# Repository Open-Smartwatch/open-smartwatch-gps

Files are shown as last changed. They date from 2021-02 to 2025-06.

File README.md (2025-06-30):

# Open-Smartwatch KiCAD files

Repo for kicad schematic, board and gerber files. This project is in development and is not ready for release.

Update 2025-06: There never was a release since the selected GPS module does not work on a wearable-sized PCB, and while worn at the same time.

## Tools

To view/modify the files from this repository, install KiCAD from: [https://kicad.org](https://kicad.org)

Also, add the following Symbol/Footprint library to KiCAD: [https://github.com/Open-Smartwatch/Kicad-Libraries](https://github.com/Open-Smartwatch/Kicad-Libraries)

## Schematic
Schematic

## Plots
front
bottom

## BOM

See: [https://htmlpreview.github.io/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](https://htmlpreview.github.io/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)

## Instagram 
https://www.instagram.com/pauls_3d_things/

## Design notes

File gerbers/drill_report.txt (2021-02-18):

Drill report for /github/workspace/osw.kicad_pcb
Created on Thu Feb 18 17:03:41 2021

Copper Layer Stackup:
    =============================================================
    L1 :  F.Cu                      front
    L2 :  In1.Cu                    in1
    L3 :  In2.Cu                    in2
    L4 :  B.Cu                      back

Drill file 'osw-PTH.drl' contains
    plated through holes:
    =============================================================
    T1  0.33mm  0.013"  (193 holes)
    T2  0.75mm  0.030"  (2 holes)  (with 2 slots)

    Total plated holes count 195

Drill file 'osw-NPTH.drl' contains
    unplated through holes:
    =============================================================
    T1  0.55mm  0.022"  (8 holes)
    T2  1.00mm  0.039"  (4 holes)  (with 2 slots)

    Total unplated holes count 12

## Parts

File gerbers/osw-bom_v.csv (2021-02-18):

Reference | Value | Package | Quantity | digikey_pn | mpn | manufacturer | digi-key_pn | manf | manf#
Unpolarized capacitor, small symbol | 10p | C_0603_1608Metric | 1
Unpolarized capacitor, small symbol | 100p | C_0603_1608Metric | 1
Unpolarized capacitor, small symbol | 0.1u | C_0603_1608Metric | 1
Unpolarized capacitor, small symbol | 0.1u | C_0603_1608Metric | 1
Unpolarized capacitor, small symbol | 0.1u | C_0603_1608Metric | 1
Unpolarized capacitor, small symbol | 0.1u | C_0603_1608Metric | 1
Unpolarized capacitor, small symbol | 0.1u | C_0603_1608Metric | 1
Unpolarized capacitor, small symbol | 0.1u | C_0603_1608Metric | 1
Unpolarized capacitor, small symbol | 0.1u | C_0603_1608Metric | 1
Unpolarized capacitor, small symbol | 0.1u | C_0603_1608Metric | 1
Unpolarized capacitor, small symbol | 0.1u | C_0603_1608Metric | 1
Unpolarized capacitor, small symbol | 0.1u | C_0603_1608Metric | 1
Unpolarized capacitor, small symbol | 0.1u | C_0603_1608Metric | 1
Unpolarized capacitor, small symbol | 0.1u | C_0603_1608Metric | 1
Unpolarized capacitor, small symbol | 0.1u | C_0603_1608Metric | 1
Unpolarized capacitor, small symbol | 0.1u | C_0603_1608Metric | 1
Unpolarized capacitor, small symbol | 4.7uF | C_0603_1608Metric | 1
Unpolarized capacitor, small symbol | 4.7u | C_0603_1608Metric | 1
Unpolarized capacitor, small symbol | 4.7u | C_0603_1608Metric | 1
Unpolarized capacitor, small symbol | 4.7uF | C_0603_1608Metric | 1
Unpolarized capacitor, small symbol | 100u | C_1206_3216Metric | 1
Unpolarized capacitor, small symbol | 100u | C_1206_3216Metric | 1
Light emitting diode, small symbol | LED_Green | LED_0805_2012Metric | 1
Generic connector, single row, 01x02, script generated (kicad-library-utils/schlib/autogen/connector/) | Conn_01x02 | PinHeader_1x02_P2.54mm_Vertical | 1
0.115A Id, 60V Vds, N-Channel MOSFET, SOT-23 | 2N7002 | SOT-23 | 1
Resistor, small symbol | 0R | R_0402_1005Metric | 1
Resistor, small symbol | 22 | R_0603_1608Metric | 1
Resistor, small symbol | 470R | R_0603_1608Metric | 1
Resistor, small symbol | 470R | R_0603_1608Metric | 1
Resistor, small symbol | 510R | R_0603_1608Metric | 1
Resistor, small symbol | 1k | R_0603_1608Metric | 1
Resistor, small symbol | 1k | R_0603_1608Metric | 1
Resistor, small symbol | 1k | R_0603_1608Metric | 1
Resistor, small symbol | 1k | R_0603_1608Metric | 1
Resistor, small symbol | 1k | R_0603_1608Metric | 1
Resistor, small symbol | 1k | R_0603_1608Metric | 1
Resistor, small symbol | 2.2K | R_0603_1608Metric | 1
Resistor, small symbol | 5k | R_0603_1608Metric | 1
Resistor, small symbol | 5.6k | R_0603_1608Metric | 1
Resistor, small symbol | 10k | R_0603_1608Metric | 1
Resistor, small symbol | 10k | R_0603_1608Metric | 1
Resistor, small symbol | 10k | R_0603_1608Metric | 1
Resistor, small symbol | 10k | R_0603_1608Metric | 1
Resistor, small symbol | 10k | R_0603_1608Metric | 1
Resistor, small symbol | 10k | R_0603_1608Metric | 1
Resistor, small symbol | 10k | R_0603_1608Metric | 1
Resistor, small symbol | 56k | R_0603_1608Metric | 1
Resistor, small symbol | 200k | R_0603_1608Metric | 1
Resistor, small symbol | 200k | R_0603_1608Metric | 1
Resistor, small symbol | 1M | R_0603_1608Metric | 1
Push button switch, generic, two pins | SW_Push | button_side_smd | 1
Push button switch, generic, two pins | SW_Push | button_side_smd | 1
Push button switch, generic, two pins | SW_Push | button_side_smd | 1
Push button switch, generic, two pins | SW_Push | button_side_smd | 1
 | BMA400 | LGA-12_2x2mm_P0.5mm | 1 | 828-1081-1-ND | BMA400 | Bosch Sensortec
 | CH340E | MSOP-10_3x3mm_P0.5mm | 1
±5ppm, I2C Real-Time Clock SOIC-8 | DS3231MZ | SOIC-8_3.9x4.9mm_P1.27mm | 1
 | GC9A01_IPS_display | GC9A01_IPS_display | 1
 | MCP73831T-2ACI_OT | SOT-23-5 | 1 |  | MCP73831T-2ACI/OT | Microchip Technology | MCP73831T-2ACI/OTCT-ND
 | PSRAM64H | SOP-8_3.9x4.9mm_P1.27mm | 1
 | Quectel_L96 | Quectel_L96 | 1
 | TPS2115A | TSSOP-8_4.4x3mm_P0.65mm | 1 | 296-16940-1-ND | TPS2115APWR | Texas Instruments
 | USB-OTG | USBmicro-B | 1
 | XC6209 | SOT-23-5 | 1
 | XC6209 | SOT-23-5 | 1
 | ttgo-32-micro | ttgo-32-micro | 1
 | SD_ebay-uSD-push_push_SMD | Conn_uSDcard | 1 |  |  |  |  | ebay | _

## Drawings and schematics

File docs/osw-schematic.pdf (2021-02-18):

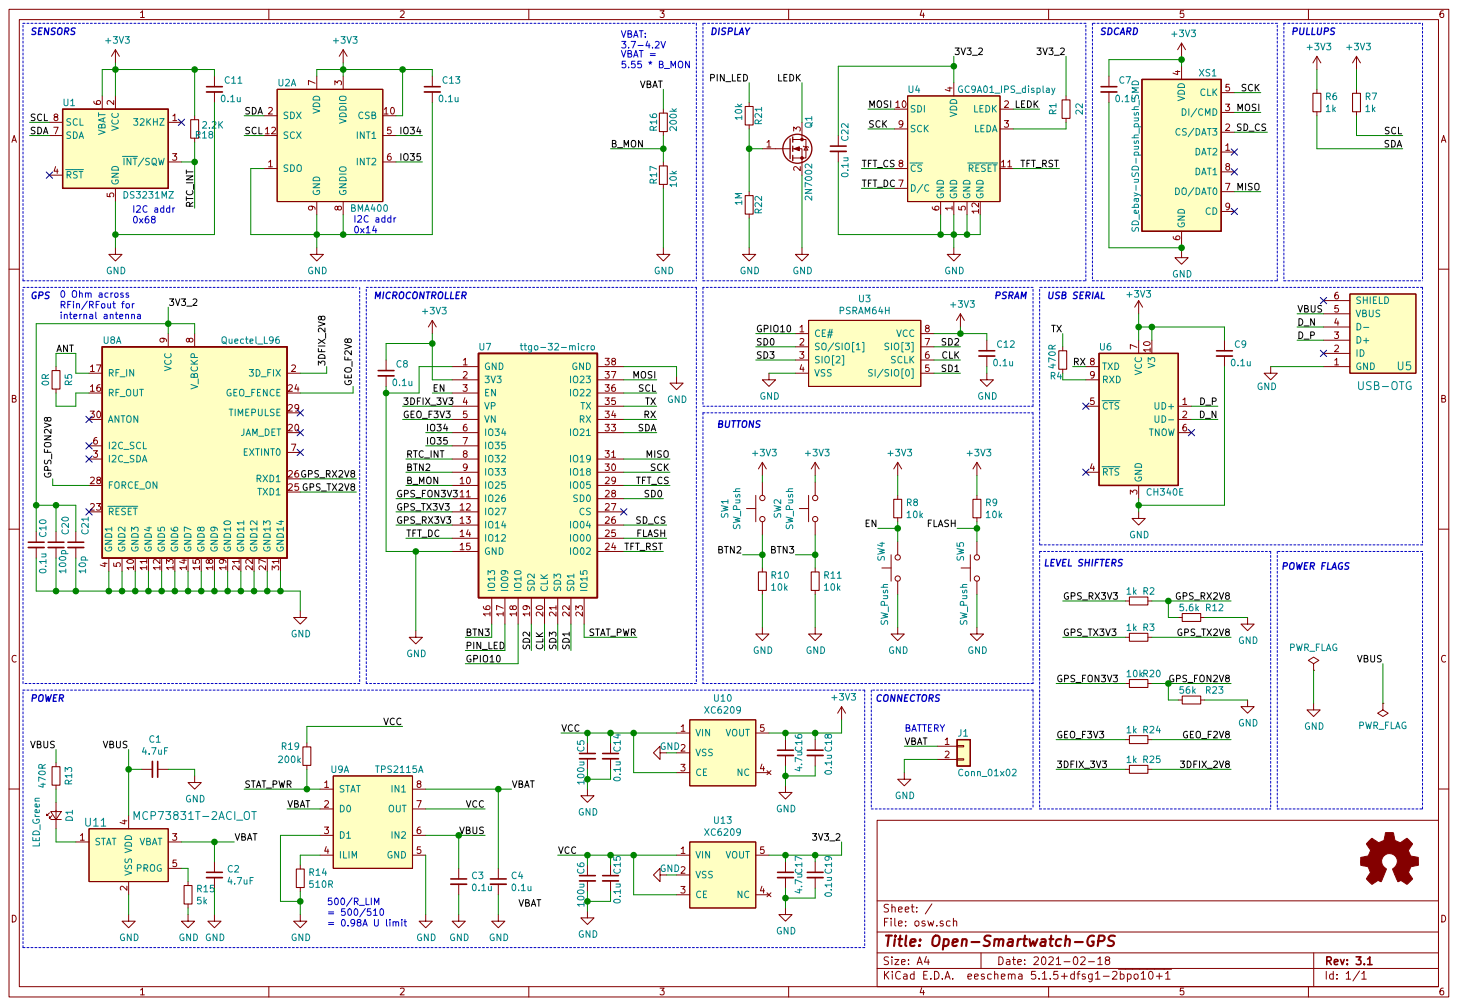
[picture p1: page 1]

6 DO/DAT0 7 DAT1 8 CD 9 XS1 SD_ebay-uSD-push_push_SMD R16 200k R17 10k GND
SCK RX MISO

6 SDA 7 SCL 8 U1 DS3231MZ GND 470R R13 EN GND

0 Ohm across RFin/RFout for

3 RTS 4 CTS 5 TNOW 6 VCC

Id: 1/1 Title: Open-Smartwatch-GPS

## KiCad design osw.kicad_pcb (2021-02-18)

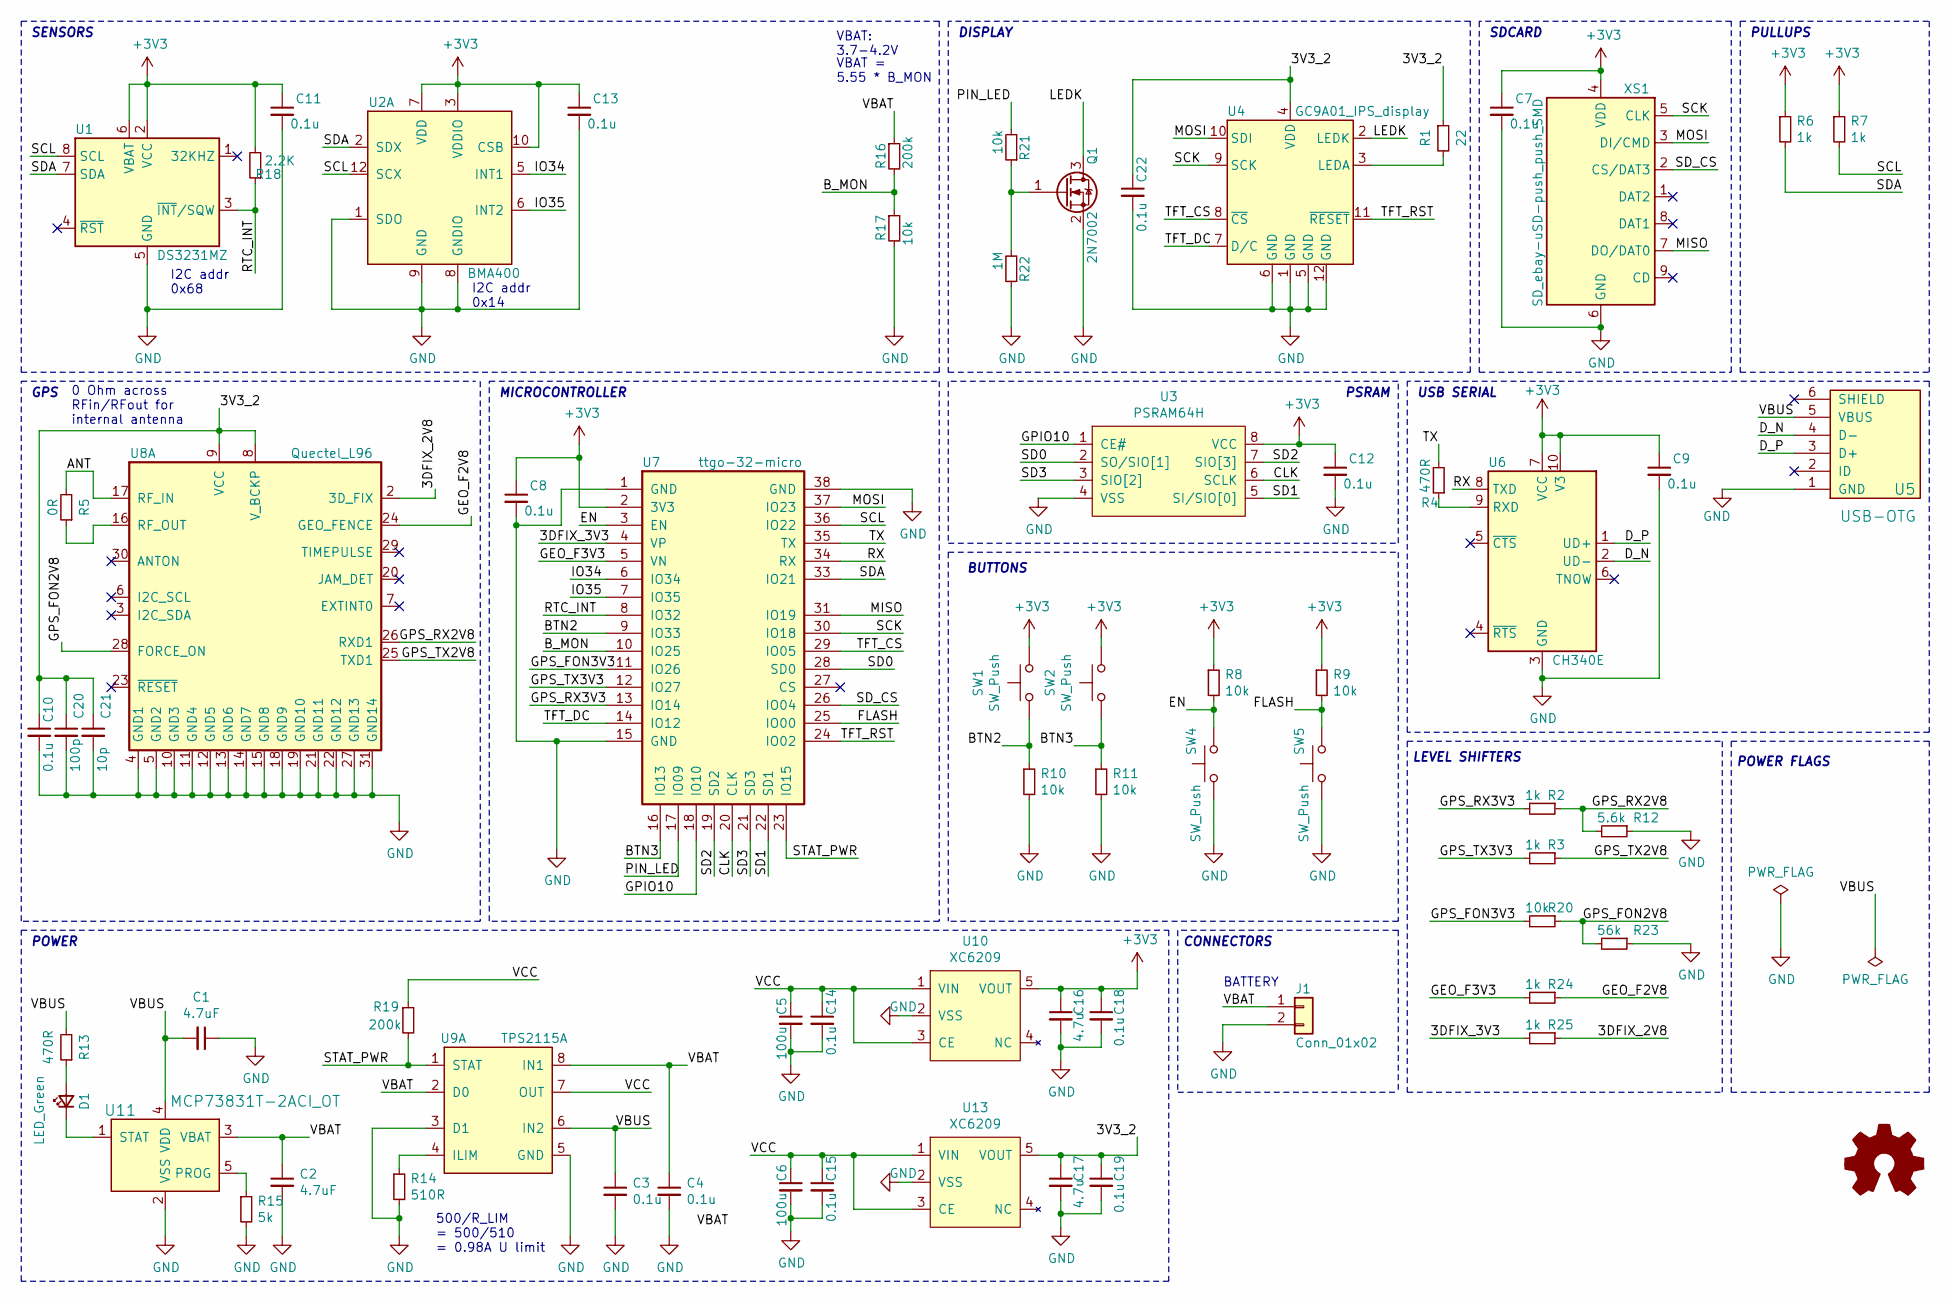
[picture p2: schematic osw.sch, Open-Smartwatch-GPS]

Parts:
C1, C2: 4.7uF; C_0603_1608Metric
C3, C4, C7, C8, C9, C10, C11, C12, C13, C14, C15, C18, C19, C22: 0.1u; C_0603_1608Metric
C5, C6: 100u; C_1206_3216Metric
C16, C17: 4.7u; C_0603_1608Metric
C20: 100p; C_0603_1608Metric
C21: 10p; C_0603_1608Metric
D1: LED_Green; LED_0805_2012Metric
J1: Conn_01x02; PinHeader_1x02_P2.54mm_Vertical
Q1: 2N7002; SOT-23
R1: 22; R_0603_1608Metric
R2, R3, R6, R7, R24, R25: 1k; R_0603_1608Metric
R4, R13: 470R; R_0603_1608Metric
R5: 0R; R_0402_1005Metric
R8, R9, R10, R11, R17, R20, R21: 10k; R_0603_1608Metric
R12: 5.6k; R_0603_1608Metric
R14: 510R; R_0603_1608Metric
R15: 5k; R_0603_1608Metric
R16, R19: 200k; R_0603_1608Metric
R18: 2.2K; R_0603_1608Metric
R22: 1M; R_0603_1608Metric
R23: 56k; R_0603_1608Metric
SW1, SW2, SW4, SW5: SW_Push; button_side_smd
U1: DS3231MZ; SOIC-8_3.9x4.9mm_P1.27mm
U2: BMA400; LGA-12_2x2mm_P0.5mm; MPN BMA400; DigiKey_PN 828-1081-1-ND
U3: PSRAM64H; SOP-8_3.9x4.9mm_P1.27mm
U4: GC9A01_IPS_display
U5: USB-OTG; USBmicro-B
U6: CH340E; MSOP-10_3x3mm_P0.5mm
U7: ttgo-32-micro
U8: Quectel_L96
U9: TPS2115A; TSSOP-8_4.4x3mm_P0.65mm; MPN TPS2115APWR; DigiKey_PN 296-16940-1-ND
U10, U13: XC6209; SOT-23-5
U11: MCP73831T-2ACI_OT; SOT-23-5; MPN MCP73831T-2ACI/OT; Digi-Key_PN MCP73831T-2ACI/OTCT-ND
XS1: SD_ebay-uSD-push_push_SMD; Conn_uSDcard

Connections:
+3V3: C7.1, C8.1, C9.1, C11.1, C12.1, C13.1, C16.1, C18.1, R6.1, R7.1, R8.1, R9.1, R18.2, SW1.2, SW2.2, U1.2 (VCC), U1.6 (VBAT), U2.3 (VDDIO), U2.7 (VDD), U2.10 (CSB), U3.8 (VCC), U6.7 (VCC), U6.10 (V3), U7.2 (3V3), U10.5 (VOUT), XS1.4 (VDD)
/3DFIX_2V8: R25.1, U8.2 (3D_FIX)
/3DFIX_3V3: R25.2, U7.4 (VP)
/3V3_2: C10.1, C17.1, C19.1, C20.1, C21.1, C22.1, R1.1, U4.4 (VDD), U8.8 (V_BCKP), U8.9 (VCC), U13.5 (VOUT)
/ANT: R5.2, U8.17 (RF_IN)
/BTN2: R10.1, SW1.1, U7.9 (IO33)
/BTN3: R11.1, SW2.1, U7.16 (IO13)
/B_MON: R16.2, R17.1, U7.10 (IO25)
/CLK: U3.6 (SCLK), U7.20 (CLK)
/D_N: U5.4 (D-), U6.2 (UD-)
/D_P: U5.3 (D+), U6.1 (UD+)
/EN: R8.2, SW4.2, U7.3 (EN)
/FLASH: R9.2, SW5.2, U7.25 (IO00)
/GEO_F2V8: R24.1, U8.24 (GEO_FENCE)
/GEO_F3V3: R24.2, U7.5 (VN)
/GPIO10: U3.1 (CE#), U7.18 (IO10)
/GPS_FON2V8: R20.1, R23.2, U8.28 (FORCE_ON)
/GPS_FON3V3: R20.2, U7.11 (IO26)
/GPS_RX2V8: R2.1, R12.2, U8.26 (RXD1)
/GPS_RX3V3: R2.2, U7.13 (IO14)
/GPS_TX2V8: R3.1, U8.25 (TXD1)
/GPS_TX3V3: R3.2, U7.12 (IO27)
/IO34: U2.5 (INT1), U7.6 (IO34)
/IO35: U2.6 (INT2), U7.7 (IO35)
/LEDK: Q1.3 (D), U4.2 (LEDK)
/MISO: U7.31 (IO19), XS1.7 (DO/DAT0)
/MOSI: U4.10 (SDI), U7.37 (IO23), XS1.3 (DI/CMD)
/PIN_LED: R21.2, U7.17 (IO09)
/RTC_INT: R18.1, U1.3 (~INT~/SQW), U7.8 (IO32)
/RX: U6.8 (TXD), U7.34 (RX)
/SCK: U4.9 (SCK), U7.30 (IO18), XS1.5 (CLK)
/SCL: R7.2, U1.8 (SCL), U2.12 (SCX), U7.36 (IO22)
/SD0: U3.2 (SO/SIO[1]), U7.28 (SD0)
/SD1: U3.5 (SI/SIO[0]), U7.22 (SD1)
/SD2: U3.7 (SIO[3]), U7.19 (SD2)
/SD3: U3.3 (SIO[2]), U7.21 (SD3)
/SDA: R6.2, U1.7 (SDA), U2.2 (SDX), U7.33 (IO21)
/SD_CS: U7.26 (IO04), XS1.2 (CS/DAT3)
/STAT_PWR: R19.2, U7.23 (IO15), U9.1 (STAT)
/TFT_CS: U4.8 (~CS), U7.29 (IO05)
/TFT_DC: U4.7 (D/C), U7.14 (IO12)
/TFT_RST: U4.11 (~RESET), U7.24 (IO02)
/TX: R4.2, U7.35 (TX)
/VBAT: C2.1, C4.1, J1.1, R16.1, U9.2 (D0), U9.8 (IN1), U11.3 (VBAT)
/VBUS: C1.2, C3.1, R13.2, U5.5 (VBUS), U9.6 (IN2), U11.4 (VDD)
/VCC: C5.1, C6.1, C14.1, C15.1, R19.1, U9.7 (OUT), U10.1 (VIN), U10.3 (CE), U13.1 (VIN), U13.3 (CE)
GND: C1.1, C2.2, C3.2, C4.2, C5.2, C6.2, C7.2, C8.2, C9.2, C10.2, C11.2, C12.2, C13.2, C14.2, C15.2, C16.2, C17.2, C18.2, C19.2, C20.2, C21.2, C22.2, J1.2, Q1.2 (S), R10.2, R11.2, R12.1, R14.2, R15.2, R17.2, R22.1, R23.1, SW4.1, SW5.1, U1.5 (GND), U2.1 (SDO), U2.8 (GNDIO), U2.9 (GND), U3.4 (VSS), U4.1 (GND), U4.5 (GND), U4.6 (GND), U4.12 (GND), U5.1 (GND), U6.3 (GND), U7.1 (GND), U7.15 (GND), U7.38 (GND), U8.4 (GND1), U8.5 (GND2), U8.10 (GND3), U8.11 (GND4), U8.12 (GND5), U8.13 (GND6), U8.14 (GND7), U8.15 (GND8), U8.18 (GND9), U8.19 (GND10), U8.21 (GND11), U8.22 (GND12), U8.27 (GND13), U8.31 (GND14), U9.3 (D1), U9.5 (GND), U10.2 (VSS), U11.2 (VSS), U13.2 (VSS), XS1.6 (GND)
unnamed: D1.1 (K), U11.1 (STAT)
unnamed: D1.2 (A), R13.1
unnamed: Q1.1 (G), R21.1, R22.2
unnamed: R1.2, U4.3 (LEDA)
unnamed: R4.1, U6.9 (RXD)
unnamed: R5.1, U8.16 (RF_OUT)
unnamed: R14.1, U9.4 (ILIM)
unnamed: R15.1, U11.5 (PROG)

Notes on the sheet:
500/R_LIM = 500/510 = 0.98A U limit
GPS
SENSORS
POWER
SDCARD
DISPLAY
USB SERIAL
BUTTONS
PULLUPS
0 Ohm across RFin/RFout for internal antenna
VBAT: 3.7-4.2V
VBAT = 5.55 * B_MON
MICROCONTROLLER
POWER FLAGS
I2C addr 0x68
I2C addr 0x14
CONNECTORS
BATTERY
LEVEL SHIFTERS
PSRAM

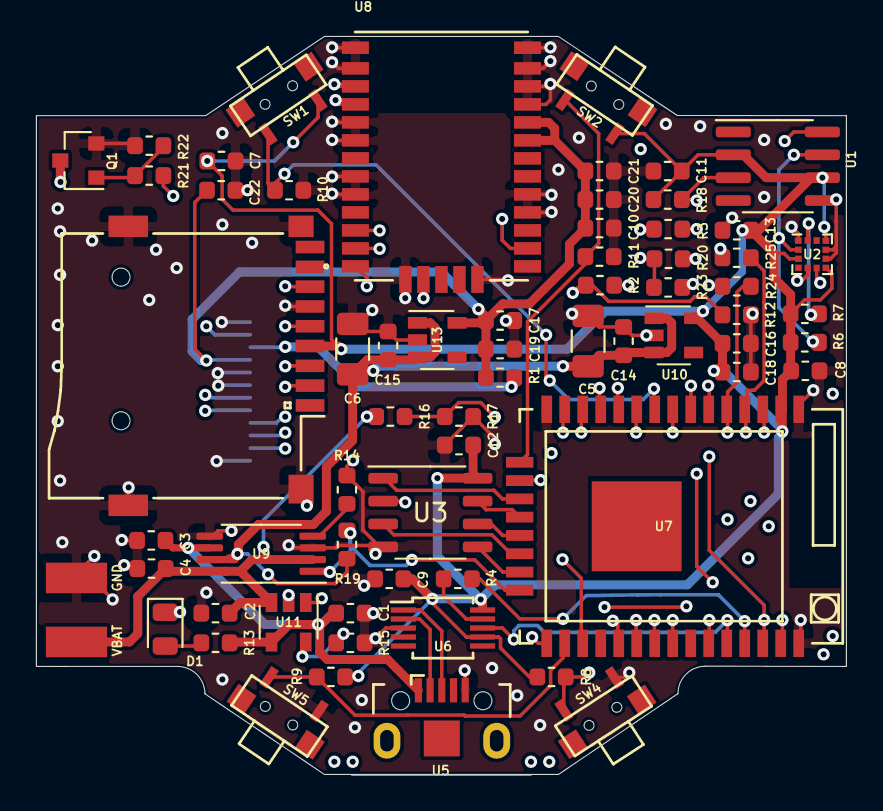
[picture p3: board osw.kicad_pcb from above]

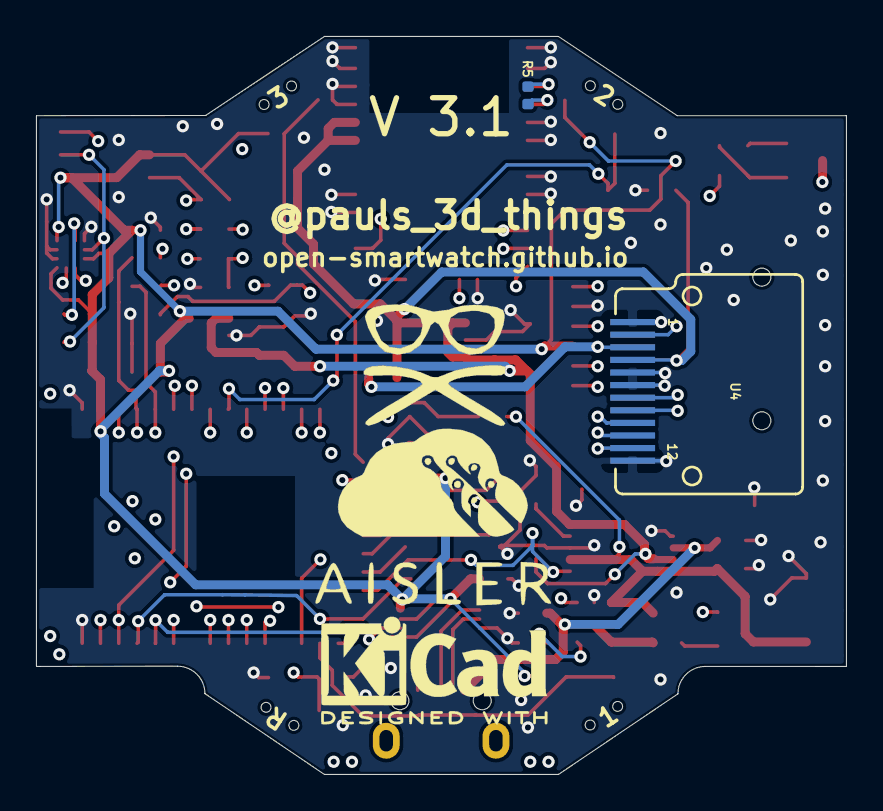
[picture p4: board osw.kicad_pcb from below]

Board: 4 copper layers, 45.0 x 41.0 mm, 67 parts (2 on the bottom side), 55 nets.

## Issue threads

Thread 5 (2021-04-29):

Vibration

rasppliances, 2021-04-29:
Hello,

Has anyone looked into adding vibration? I know any motor would add size to what is already a good sized watched, but if you don't have vibration, getting notifications on your watch won't help.

I think that a small transistor could be added to the circuit board, hooked up to an open GPIO (assuming there is one), and used to control vibration through PWM.  We could add an osw_vibration library to be included in apps.  I imagine the call would be really simple, like doVibration(intensity, duration);  Maybe it could even go into osw_ui_util.cpp (I know it's not a graphical UI element, but it is a UI element since it's interacting with the user:) ).

Rick

rasppliances, 2021-04-29:
I don't know about how the traces would have to be rerouted, but could the transistor be added to the lite edition if the open hardware logo were either smaller or switched to the back?

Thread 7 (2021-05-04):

Proposal: heart rate monitor

d1nuc0m, 2021-05-04:
Hello,
as of title I would like to make a proposal: have you thought about adding an heart rate monitor? It would be useful to use the smartwatch for sports.
Thank you

baptistedftn, 2021-06-30:
Maybe we can use a MAX30102 sensor which works with I2C interface

Kreyren, 2022-01-20:
Was this proposal accepted or is anyone working on it?

d1nuc0m, 2022-01-23:
> Was this proposal accepted or is anyone working on it?

I don't know, we should ask @uvwxy @OneGneissGuy @nerdyscout

uvwxy, 2022-01-23:
Waiting on V4.1 light edition pcbs. Will have gnd, 3v3c, sda, scl pad underneath to enable extensions, such as hr monitor

OneGneissGuy, 2022-01-23:
We could hack one in the mean time?

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

Kreyren, 2022-01-23:
How should we decide which heart rate monitor components are compatible with the design? As there is a lot of them that seems to have various known and unknown problems.

Maybe we should make a some kind of list for those that work with the pcbs?

OneGneissGuy, 2022-01-23:
The discord server is the best place to discuss imo

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

a-allard, 2023-11-04:
If it is of interest development has started on a new rev [here](https://github.com/a-allard/open-smartwatch-gps).

There is an HR monitor on the board.  I don't know if it will work or not yet do to placement and I still need to redesign the case.

Also the HW design linked above has not been tested yet.  I have boards on order to test when they arrive,

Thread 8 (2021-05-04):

Flashlight app?

Pescatore04, 2021-05-04:
I don't know how to code this and it goes against all the power saving efforts for such wearable.  However, turning on all pixels white at low intensity might be a useful light source.
IIRC, there is a fixed pull-up for the backlight, so adding a LED controller, or via PWM would provide a settable intensity.

BenjaminSchlechter, 2022-04-28:
That's a great idea and to get started developing apps for the osw i decided to implement this.

For the intensity i set the default to max as the display isn't emitting as much light as a lamp - however for indoor usage at night i think it's good enough. I haven't digged into the hardware/PWM thing and just used the software HAL (hardware abstraction layer), i.e.: hal->setBrightness(255);

With Button 2/3 you can change the color (default behaviour) or the intensity (use '#define CHANGE_COLORS_INSTEAD_OF_BRIGHTNESS 0' in your config.h). Of course the display intensity is restored to it's previous state when switching to the next app/watchface. With the color changig mode this watchface can be used to detect dead pixels as well.

I didn't want to fork the repo and make a proper pull request, therefore i made a patch for anyone to use (which github doesn't allow as attachment...): Therefore unzip the patch in your open-smartwatch-os repo directory, apply it with git apply OswAppLamp.patch and add '#define TOOL_LAMP 1' to your config.h file in the include/ subdirectory. Then you're ready to go (which means running 'pio run -t upload' of course).

The patch:
[OswAppLamp.patch.zip](https://github.com/Open-Smartwatch/open-smartwatch-gps/files/8586753/OswAppLamp.patch.zip)

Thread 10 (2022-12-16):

Future dev

a-allard, 2022-12-16:
Hi @uvwxy

It looks like it's been awhile since this project has been updated.  I started looking at building one of these when I noticed some parts have gone obsolete.

Would it be helpful if I fork this project and update the board to replace obsolete parts and potentially solve some of the other issues/

Let me know

a-allard, 2022-12-27:
If it is of interest here is what I've been doing: https://github.com/a-allard/open-smartwatch-gps

simonmicro, 2023-10-18:
Basically, did you ever get it working? The last update for me was, that the antenna was so bad (placed, configured, everything) that we basically never received the satellites while wearing on the arm...

a-allard, 2023-10-19:
Gotcha.  I never actually finished the layout I started as I wanted to know what might need to be changed.  And verify there was some interest in having a new rev of this done.

I'll a good look at the current layout in a bit (probably this weekend) and see what if anything might help the GPS.  Just to be sure we're on the same page, you are talking about the GPS antenna... Correct?

Is there anything else you want to change on this while I'm digging though this project?

simonmicro, 2023-10-29:
> you are talking about the GPS antenna... Correct?

Yes.

> Is there anything else you want to change on this while I'm digging though this project?

Well, currently a new hardware release is the most wanted request from the community - so if you feel you are up to it, go ahead :stuck_out_tongue_winking_eye:

a-allard, 2023-10-29:
:laughing:

Alrighty.  I ordered boards yesterday.

I'll let you know how they work after I get them up and running.  Probably will be 2-3 weeks, and some mods to the os.

The complete BOM and such is up on the fork of this repo.  I'll update the gerbers later today.

a-allard, 2024-01-14:
For anyone following this issue a quick update:

I did spin a board and get it back.  I had an issue with the ESP32 footprint.  Unfortunately the issue shorted VDD to GND.  So I was not able to test anything.  I have a repin going but due to the amount of time it takes to get bards from China and the Chinese New Year is coming up shortly I don't think I'll get boards back for this respin until March or April.

mantis964, 2025-06-27:
> For anyone following this issue a quick update:
>
> I did spin a board and get it back. I had an issue with the ESP32 footprint. Unfortunately the issue shorted VDD to GND. So I was not able to test anything. I have a repin going but due to the amount of time it takes to get bards from China and the Chinese New Year is coming up shortly I don't think I'll get boards back for this respin until March or April.

hey.. any update?

uvwxy, 2025-06-30:
I stopped working on a GPS variant of the board. It never worked while worn since the GPS module requires a far larger GND plane to work.

a-allard, 2025-07-10:
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

I put this project aside after the original project went behind a paywall.  Kind of silly to help support the hardware as it becomes a competition at that point.

uvwxy, 2025-07-10:
https://www.patreon.com/posts/121175070

Closed 2025-07-10.

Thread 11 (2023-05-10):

how to edit pcb

ersaayan, 2023-05-10:
I use fusion360. hot to open gerber file and edit. if you know solution please help me :)

a-allard, 2023-08-28:
You won't be able to edit the PCB in fusion.
You'll need to install kicad.

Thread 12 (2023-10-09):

Regarding hardware upgrades, such as type-c interface

GreenShadeZhang, 2023-10-09:
Is this project still being updated? I see that the hardware version is a long time ago. I want to reproduce a finished product, but the hardware feels a bit old, so I would like to ask if there is a timeline for this hardware update.

a-allard, 2023-11-03:
@GreenShadeZhang

This project has been quiet for quite some time.  As mentioned in #10 I forked this and started a new [revision of the hardware](https://github.com/a-allard/open-smartwatch-gps).  I have not yet tested it as the boards are finally in production.  Once I have them tested and get a fork of the OS running I'll update the fork of this repo with info on building.

GreenShadeZhang, 2023-11-07:
> @GreenShadeZhang
>
> This project has been quiet for quite some time. As mentioned in #10 I forked this and started a new [revision of the hardware](https://github.com/a-allard/open-smartwatch-gps). I have not yet tested it as the boards are finally in production. Once I have them tested and get a fork of the OS running I'll update the fork of this repo with info on building.

This sounds great, I think it would be a great toy if the GPS and circuit board worked properly, looking forward to your results.

samuk, 2024-01-30:
How feasible would it be to do a variant based on https://store.rakwireless.com/products/wisduo-lpwan-module-rak11300?m=3&h=wisduo-modules-for-lorawan you'd lose wifi, but gain LoRa

a-allard, 2024-01-31:
@samuk

Such a variant looks to be possible.  But the FW would require a complete rewrite from the ground up.  The FW rewrite is not something I am up for.
As well as you'd be relying on always having a LoRa network to connect to.  As things are now most everyone has a WiFi network to connect to but I doubt the majority of people have access to LoRaWAN.  That said, battery life might, I stress might as RAK does not say anything about battery life at all, improve as LoRa tends to be lower power than WiFi.

So, I am not opposed to doing the HW design.  But someone else will have to write the FW for it.

samuk, 2024-01-31:
That would be very interesting to me.

My use case would be using the watch as a basic watch & LoRa tracker. The firmware would essentially be https://meshtastic.org/docs/hardware/devices/rak/core-module?rakcore=RAK11310#rak11310---rp2040

The Twatch is already supported, but closed hardware and the ESP32 makes it power-hungry https://meshtastic.org/docs/hardware/devices/twatch/

With some additional UI stuff to tell the time. Meshtastic already has various UI's, including a clock, so I think it's fairly feasible.

samuk, 2024-01-31:
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

What might actually make sense is designing a watch for the generic [Wisblock connector](https://store.rakwireless.com/products/wisblock-core-modules?variant=42440630304966)

It would then be up to users which module they used (STM, NRF52, RP2040, ESP32) if users wanted to use a variant of the existing firmware they could get the ESP32 module, or for Meshtastic based firmware one of the LoRa modules.

The Wisblock boards are a little larger, but might actually leave more space for routing on the watch PCB as they are separate from it?

a-allard, 2024-01-31:
2 issues with using the generic Wisblock FP.

The display connector is 2.1mm high.  The Wisblock connector is only 0.8mm high.  So the Wisblock would collide with the display connector before it was correctly seated.  Even if you rotated the Wisblock 90 degrees so the connector was directly above the display connector the other end would stick beyond the edge of the watchy current size.

The other issue is when trying to add a module in the battery gets displaced this means the case gets significantly thicker.  Not the end of the world but it won't fit the watchy current case design.

Also the Wisblock has mounting screws to hold it in place.  Those are going to be an issue getting them in an area that does not harm the display.  Or leave them out and make the case hold the Wisblock with a tension fit which gets tricky due to mechanical tolerance stackup.

Watchy is nice and small because there are no modules on it and it does not support GPS.  To pull in a relatively large module (Wisblock) is going to swell the board beyond the current watchy outline.  The way to get a watchy sized device that supports LoRa would be to design a new version of Watchy with the guts of the RAK11310 directly laidout on the board and drop the GPS module and SD card from this design.  That would make doing something like a watchy sized device probably doable.

So, if you want a Wisblock module based watch and are willing to dump the GPS and SD card support it will still be larger than watchy but I can see what it looks like.  If you want the GPS and or SD card it is definitely going to be larger than watchy.

samuk, 2024-01-31:
" Even if you rotated the Wisblock 90 degrees so the connector was directly above the display connector the other end would stick beyond the edge of the watchy current size."

By my measure you _just_ get the required 20mm? It would be tight, but possible? The e-ink could even be brought down ~1mm lower maybe?
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

I'd be happy to dump the SD personally, but the GPS is what would turn it into a useful tracker for my particular use case.

How large are the smallest (useful) GPS devices? Shall I do a bit of research?

a-allard, 2024-01-31:
That might fit with a bit of shoehorning. The GPS will be crazy tight.

So all passives will be 0201s for space reasons. So hand assembly will be very difficult if possible. Not sure if you're planning to order fully assembled from pcbway or doing any hand assembly.

I won't have time to really look at this for a few weeks. But I might be able to do a course feasibility test.

samuk, 2024-01-31:
That would be great. I'd use JLPCB assembly, so basic parts from LCSC would be a bonus.

If it did end up too fat for the cases we might get away with a spacer and longer screws?

a-allard, 2024-01-31:
Alright. I'll have to remember what JLC limitations are.

That might be feasible. I don't know enough about how watchy mechanical assembly is designed to give a solid answer.

It'll be a bit getting this setup. When I get the new repo setup I'll ping you so you can follow as things progress provided the initial fit test looks good.

That said the WiFi version I started will take precedent when the boards come in.

samuk, 2024-01-31:
Nice, thanks. I'll do a bit of research on GPS it's not an area I know much about. This[ MAX2769BETI/V+T ](https://www.lcsc.com/product-detail/Satellite-Positioning-Modules_Analog-Devices-Inc-Maxim-Integrated-MAX2769BETI-V-T_C118482.html) teensy for example, but not sure about codebase etc.

Szybet, 2024-01-31:
Cool things, cool things
> You only get ~12cm below the e-ink connector to place a GPS module though. I don't know if that's adequate?

Below the e-ink connector goes the e-ink flex cable so...

well if you are looking for space on the PCB I would propose:
- Replace the battery charging circuit with something smaller
- Remove the accelerometer IC
- Remove the buzzer as already mentioned
- smaller battery connector?
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
samuk, 2024-03-25:
I think we're imagining that most programming/debugging will happen off-device. These [modules](https://store.rakwireless.com/collections/wisblock-core) (which may or may not be ESP32) can be dropped into one of the [existing carriers](https://store.rakwireless.com/collections/wisblock) for much software work. Some good test points are definitely desirable though, space permitting.

If we get to a working prototype based on Watchy dimensions I'd call that a win. My particular use case is mostly as an off-grid child tracker device. Last year I used a [T-echo](https://www.lilygo.cc/products/t-echo) so this 'watch' would already represent a significant miniaturization of that LoRa mesh functionality.

a-allard, 2024-03-25:
@Szybet to get a smaller form factor for the watch would require a couple things, first not using the modules as direct PCB mounted HW usually is smaller than having modules.  The second thing would be a different display.  The size of watch is primarily dictated by the display.

The original goal of the RAK project is to be based on the module.  So going smaller is a hard no.

If you find a smaller display we can talk about another custom spin of watchy adding test points and shrinking the board (though I don't know how much we can actually shrink it without setting up a new project)

@samuk
I'll get the holes put in tonight.  I wouldn't use the RAK module hole for mounting as it is pretty small but if it works and doesn't torque the module too much (I'd imagine you'll have to play with it to find out)
Do you have a particular hole size in mind?  Or just whatever watchy used?

samuk, 2024-03-26:
It looks like the current 'slot' is 2mm, so that should work

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

a-allard, 2024-04-06:
@samuk

Layout is done.  I might make a couple more tweaks in the next couple days.  Let me know if there is anything missing or wrong.  It is quite tight.  Once you've checked it and I've looked it over again I'll put in all the info needed to get it manufactured.

samuk, 2024-04-06:
How exciting! Well done.

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

I think you need to do a push to github before I'll see it though.

a-allard, 2024-04-06:
I forgot I was on the alt branch still.  Now updated on master you should be good.

samuk, 2024-04-06:
Wow nice, It's looking great! I appreciate how much work that will have been..

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

I guess the next step is to make a couple and see if they actually work with the default Meshtastic firmware, I can then tweak the software from there for e-ink etc

a-allard, 2024-04-06:
That's weird.  Fixed now though.  I updated the pdf schematic and exported an html BOM.  As well as put in the layout on the drawing layer the stackup and characteristics tables.  I have a copy in pcbway to see if they are okay with the design and if the BOM checks out.  it should but I wanted to double check.

I think you should be a go.  I'd advise going to pcbway as I have had better luck with them and they are not much more that jlcpcb last time I checked.  If you choose to use jlcpcb there are a few parts you'll have to figure out suitable substitutes for.  Once pcbway approves it I'll share the design so you can just order rather than having to manually enter all the parameters.

Otherwise let me know if anything else is missing.

samuk, 2024-04-06:
Nice, waiting for PCBway review now, I ordered a case/strap/battery.

I documented the bit's I'm ordering here: https://openmeshwatch.github.io/ I sent you an invite to that organisation/repo if you want to make any changes to that page [here](https://github.com/openmeshwatch/openmeshwatch.github.io/blob/master/index.md)

samuk, 2024-04-08:
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

These are the parts that I'm struggling to find. In some cases I'm struggling to even find the original via google.

I'll keep trying with it, but if you're able to provide any of the missing Cxxx LCSC part numbers in the right column of this then that would be great https://github.com/openmeshwatch/OSW_rakWisblock/blob/master/production/bom.csv

a-allard, 2024-04-10:
Sorry for the delay. Been a bit crazy with the solar eclipse.
I'll have a look later this week.

samuk, 2024-04-10:
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

These are the remaining unmatched parts, I can try their global sourcing, but I expect that will be slow/expensive.

a-allard, 2024-04-11:
* LCSC number for J1: C691131
* LCSC number for C31,C32: C5646770
* LCSC number for J5: 7407277

L2 I'll have to see if LCSC makes something similar.  This looks like it might work: https://www.lcsc.com/product-detail/Power-Inductors_SXN-Shun-Xiang-Nuo-Elec-SMNR4020-10UH_C135263.html  But it is a different size so they might not like the footprint.

samuk, 2024-04-11:
Nice, thanks.

a-allard, 2024-04-13:
R7: [C1512948](https://www.lcsc.com/product-detail/Chip-Resistor-Surface-Mount_PANASONIC-ERJ-XGNF1002Y_C1512948.html)

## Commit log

2021-02-12 finalize rev 3.0
    [osw.kicad_pcb, osw.sch]
2021-02-18 rev 3.1 - remove pull up - fix ttgo32 footprint
    [osw.kicad_pcb, osw.sch]
2021-02-18 fix page metadata
    [osw.kicad_pcb]
